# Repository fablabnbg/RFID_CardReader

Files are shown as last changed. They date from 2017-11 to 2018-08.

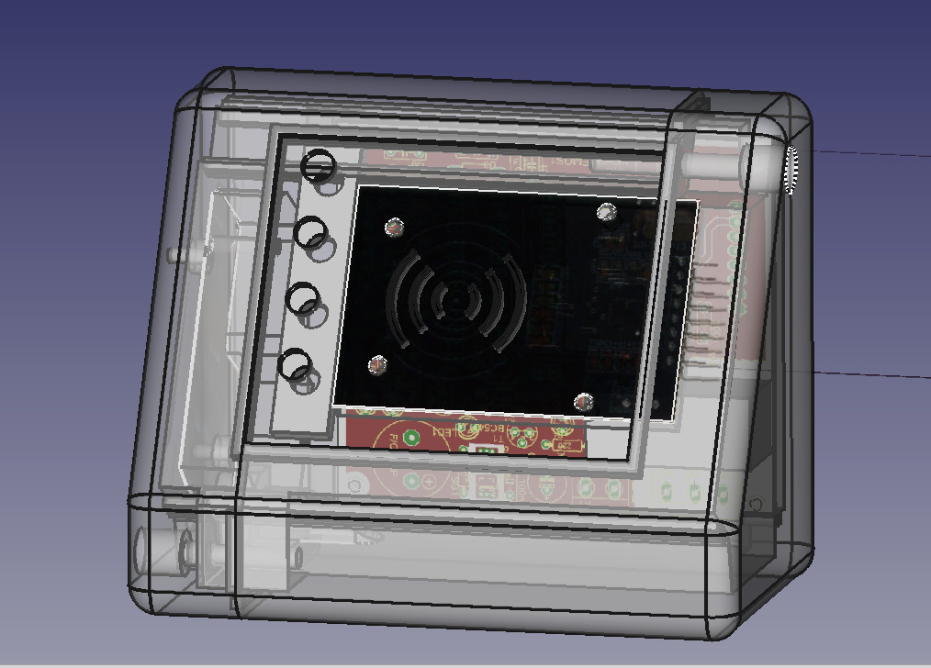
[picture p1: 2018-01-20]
mechanics/gehaeuse_freecad.jpg

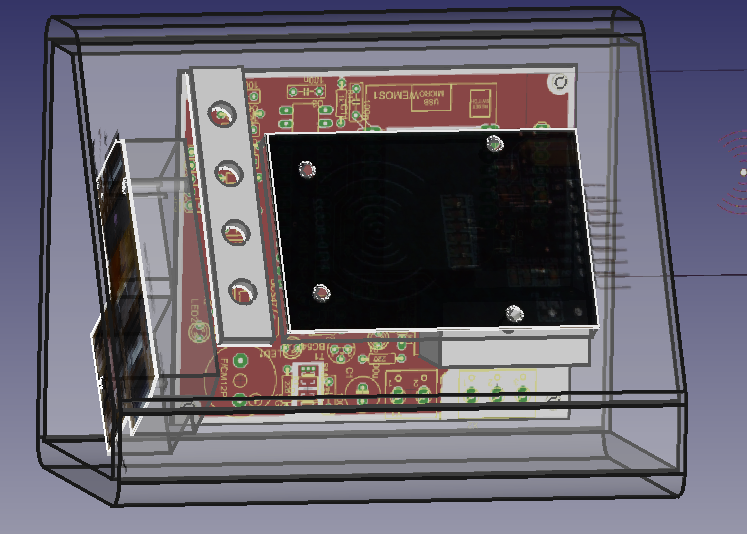
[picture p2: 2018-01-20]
mechanics/Gehäuse-2018-01-03.png

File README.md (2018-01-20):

# RFID_CardReader

A device to read member cards and activate peripheral devices.

## Documentation / Requirements
- See [doc/](doc/) subdirectory for requirements, concepts and schematics

## Software

### ESP
- Example software in subdirectory [Software_ESP](Software_ESP)
- To be built with platformio
- Use "Automaton" library for state machine and WiFi / HTTP connectivity
- Continious integration on travis-ci: 
- For details see [Software_ESP/README.md](Software_ESP/README.md)

### Webserver
 - not yet implemented
 - planning: Use simple server on Raspberry PI

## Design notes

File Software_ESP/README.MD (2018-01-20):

# Software for ESP8266 (Wemos D1 Mini)

## Build

The software should be built with [platformio](http://platformio.org/get-started/cli).

### Prerequisites:

* platformio is installed.
* If necessary, adapt `platformio.ini` to your needs (reset-method, flash-size)`. (Current version is preconfigured for Wemos D1 Mini)
* rename `example_config.h` to `config.h` and edit it to enter your WiFi SSID and password.

### Build on command line:
  * `pio run -t upload`
  * If you want to build, but no upload, enter `pio run`
  
### Build in IDE:
  * You can use Atom or VSCode with installed platformio extension.

## Dependencies

**All dependencies are installed with platformio,** so there is no need to install them manually.

### Automaton

[Automaton](https://github.com/tinkerspy/Automaton/wiki) is a *Reactive state machine framework for Arduino*.
The RFID Cardreader uses automaton to implement the state machine and the to detect the events that trigger state transitions.

*Note:* As the original version support only I/O signals on the internal GPIO pins, currently a [fork](https://github.com/euphi/Automaton) of Automaton is in use.

### Automaton-ESP8266
[Automaton-ESP8266](https://github.com/tinkerspy/Automaton-Esp8266/wiki) is an extension to Automaton to use the event/connector mechanism of Automaton for WIFI Connection and HTTP Client.

*Note:* As the original version has major bugs, currently a [fork](https://github.com/euphi/Automaton-Esp8266) of Automaton-ESP8266 is in use.

### MFRC522

Library to support MFRC522 RFID Reader on SPI.

###	Adafruit MCP23017 Arduino Library

Library to support MCP23017 I/O expander on I2C.

## Software Architecture

### main.cpp

main.cpp defines instances of the MFRC522 card reader and its own state-machine ATM_RFID_Relay as global variables.

#### `setup()`
The `setup()` functions initializes SPI and I2C, "begins" the state machine and starts the WiFi connection and connects the related events (connected, connection lost) to the triggers of the state machine:
```C++
	wifi.begin( ap_ssid, ap_password )
        // NOTE: LED_BUILTIN is RX (UART) on ESP-12, so this interferes with Serial communication on
        // ESP-12 modules (including most Wemos D1, because they also use ESP-12)
        .led( LED_BUILTIN, true ) // Esp8266 built in led shows wifi status
        .onChange(0, relay, ATM_RFIDRelay::EVT_EV_CONNLOST) // directly send an Event from Wifi the the relay state machine
        .onChange(1, relay, ATM_RFIDRelay::EVT_EV_CONNECTED)// "sub-slot" 0: Connection lost; 1: Connected
        .start();
```
  
#### `loop()`

The `loop()` functions cycles the automaton framework, then checks the card reader for new cards and if a new card is present, triggers the state machine with a new request including the UID of the card as parameter.

### ATM_RFIDRelay

This is the state machine class for automaton. So it's derived from Automaton's `Machine` class and adds the `enum`s for states and events.

#### ATM_RFIDRelay.h

The skeleton was created with the [online state machine editor](http://www.wolkendek.nl/atm/index.php) for Automaton.

As private members it defines timers, an instance of the MCP23017 IO expanders, a HTTPClient instance, an input button, and the outputs (LED, Switch, buzzer).

#### ATM_RFIDRelay.cpp

`ATM_RFIDRelay& ATM_RFIDRelay::begin()`
Here the state table is initialized and the sub-statemachines (timers, outputs, inputs, HTTPClient) are configured.

`int ATM_RFIDRelay::event( int id )`

This method is called from the automaton framework every cycle for each possible trigger event. If it returns true the event is triggers.
In ATM_RFIDRelay this is used for the timers only as all other events are triggered externally.

`void ATM_RFIDRelay::action(int id)`

For each state, Automaton allows to define a function for entry, loop or exit.
ATM_RFIDRelay uses this to set the outputs according to the current state.
The automaton "ATM_Led" class allows to set an output to a blink pattern, this is used for some optical or accustical feedback.

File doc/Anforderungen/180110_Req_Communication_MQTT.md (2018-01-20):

# Principle

All communication between the RFID-Cardreader (reader) and the controller is done via MQTT.

Communication follows the [Homie Convention](https://github.com/marvinroger/homie).

If the reader needs to authorize a user, it MUST send an authorisation request to the controller. 

The controller MUST answer the request with an appropriate command to the controller. 

# Homie convention

* The base topic is up the installation. It is recommended to use own base topics for the network of RFID-Cardreaders, e.g. `FLN-Machines`.
* Each device SHOULD be named according to the machine it controlls, e.g. `ZingLaser`.
* *Note: Following the homie convention includes all the default communication from Homie and its Homie-ESP8266 implementation, e.g. advertising of Nodes, frequent information about WiFi quality, uptime, OTA support etc.*

## Nodes

* There MUST be an `AuthReq` node with the property `Token`.
* There MUST be an `State` node with the property `Alert` and the *settable* property `Relais` 
* Other nodes MAY be defined, e.g. to use the device for other functions (e.g. temperature, or current measurement etc.).

## Properties 
### Token (Node Authreq)

* Datatype uint32, no unit

### Relais (Node State)
* Datatype string, no unit
* The string to set the property (controller to reader) MUST be one of the following *enumeration*:
  * `ON_Authorized`: The user has been authorized, so the relais must be switched on.
  * `ON_Override`: The relais must be switched on, although no authorization was requested (override function from server).
  * `OFF_Rejected`: The user has been rejected
  * `OFF_Override`:  The server commands the relais to be switched off.
  * `OFF_locked`: The server commands the relais to be switched off and there SHOULD be no request from the reader to switch it on again (this also SHOULD be visualised on the reader).
  * `OFF_unlocked`: Used to reset the locked state.
* The string to tell the property to the conroller MUST be on of the following *enumeration*:
  * `ON`
  * `OFF`: The relais is off. This includes local reasons to switch the relais off.
  * `ON_override`: The relais has been overridden locally.  
  * *optional* @@@TODO@@@: `OFF_timeout`: The relais has been switched off due to timeout

### Alert
* Datatype: string, no unit
* The string informs the controller of an alert:
  * `OK`: No alert
  * `Intrusion`: Intrusion contacts open
  * @@@TODO@@@: `Override` (this informationis redundant to the Relais state ON_override)
  * Other strings MAY be defined, e.g. `overcurrent`, `powerfail` etc.

## Example:
  
 The base topic is `FLN-Machines` and the device is `Coffee`.
  
 The card reader reads a card of a user that is allowed to use the machine. An authorisation request with the token `CAFEBABE` is to be sent.
 
 Direction           | MQTT Topic                          | MQTT Message
 --------------------|-------------------------------------|-----------------
 reader -> controller|FLN-Machines/Coffee/AuthRequest/Token| CAFEBABE
 controller -> reader|FLN-Machines/Coffee/State/Relais/set | ON_Authorized
 reader -> controller|FLN-Machines/Coffee/State/Relais     | ON
 
 The card reader reads a card of a user that is NOT allowed to use the machine. An authorisation request with the token `ABADCAFE` is to be sent. 

 Direction           | MQTT Topic                          | MQTT Message
 --------------------|-------------------------------------|-----------------
 reader -> controller|FLN-Machines/Coffee/AuthRequest/Token| ABADCAFE
 controller -> reader|FLN-Machines/Coffee/State/Relais/set | OFF_Rejected
 reader -> controller|FLN-Machines/Coffee/State/Relais     | OFF

  # Security
  
  ...tbd...
  
  Keywords:
    * RFID-Security out of scope of communication spec
    * WiFi with strong passwords, on Wifi for machines
    * MQTT TLS (as soon as available in Homie-ESP8266
    * MQTT user authentication
    * MQTT ACLs for topics

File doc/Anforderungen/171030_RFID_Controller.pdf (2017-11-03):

171030_RFID_Controller.docx | 30.10.2017

Roman Jost
Version: v0.1 | 1 / 4 | FabLab Nürnberg

# RFID Control Unit

Technische Spezifikation

Version | Autor | Info
0.1 | RJ | Erste Version. Erstellung einer technischen Spezifikation.

## Inhalt

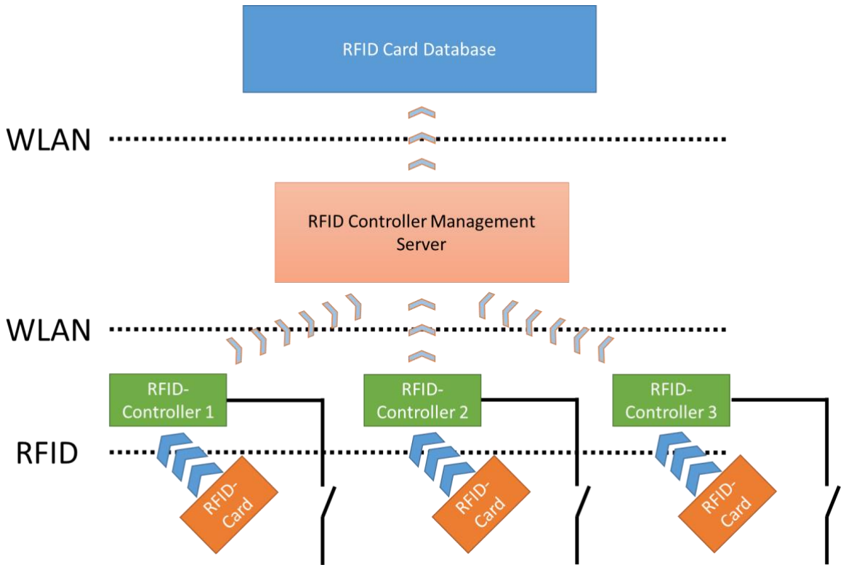
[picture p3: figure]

Version: v0.1 | 2 / 4 | FabLab Nürnberg

## 1.Motivation

Viele Arbeitsplätze und –geräte im FabLab Nürnberg sind ohne Einschränkungen nutzbar, obwohl zum sicheren und pflichtbewussten Arbeiten eine Einweisung nötig wäre. Zudem werden Arbeitsplätze regelmäßig verlassen, ohne für die gewünschte Sauberkeit zu sorgen. Der Verursacher ist in den meisten Fällen nicht mehr nachzuverfolgen.

Ein Lösungsansatz um die aufgelisteten Probleme zu entschärfen ist ein RFID Controller. Dieser Controller ist ein eigenständiges Gerät, welches die RFID Mitgliedskarten einlesen kann. Die so gewonnenen Informationen werden an einen zentralen Server übergeben, welcher die Berechtigungen des Mitglieds dem Controller übermittelt. Abhängig von den Berechtigungen kann der Controller nun entweder die Benutzung gewähren oder verweigern.

Der RFID Controller kann vielseitig eingesetzt werden:

- Freischaltung von Geräten.
- An- und Abmeldung von Mitgliedern an Arbeitsplätzen.
- Entriegelung von abgeschlossenen Objekten (Schlüsselkasten, Kühlschrank)

Anhand eines Logbuchs auf dem Server kann zudem jederzeit nachverfolgt werden, welches Mitglied wann eine Anfrage bei einem der Controller gestellt hat.

## 2. Technische Spezifikation

### 2.1 Übersicht

Einzelne RFID-Controller kommunizieren mittels Funkverbindung (Vorzugsweise WLAN) mit einem Server. Der Server kann an einer weiteren Stelle die Berechtigungen des Mitglieds anhand der Karten-ID feststellen und ein Access/Deny an den Controller zurücksenden.

Version: v0.1 | 3 / 4 | FabLab Nürnberg

Sobald der Server eine positive Antwort zurück sendet, kann der RFID-Controller die Peripherie freigeben.

### 2.2 Hardware

Der Hardware Controller soll im Wesentlichen aus zwei Modulen bestehen: Als Mikrocontroller kommt der ESP8266 zum Einsatz. Dieser verfügt über ein integriertes WLAN Modul und eine SPI-Schnittstelle. Via WLAN wird mit dem Server kommuniziert, die SPI-Schnittstelle dient zum Datenaustausch mit dem RFID Modul. Das RFID Modul ist ein MFRC522, dieses wurde schon bei der Tür-Schließanlage am FabLab Eingang eingesetzt und hat mit seiner fehlerfreien Arbeitsweise überzeugt. Zudem gibt es schon eine fertige Bibliothek mit Beispiel-Applikationen für das MFRC522.

Weiterhin sollen noch folgende Eigenschaften realisiert werden:

| • Eine Power LED → Betriebsspannung OK • Eine „Connection to Server“ LED → Verbindung zum Server aktiv • Eine „Transmit Receive“ LED → Daten werden übertragen (Eine LED für beide Richtungen) • Eine „Status“ LED → „Gerät / Arbeitsplatz freigeschaltet“ • Im Störungsfall soll durch einen kleinen Hardware Eingriff der Controller überbrückt werden können. Dies könnte man durch einen Jumper oder Mikroschalter umsetzen. Dieses Bauteil sollte jedoch nicht so einfach zugänglich sein, sodass die Controller-Module nicht ständig überbrückt werden. Die Überbrückung sollte so aufgebaut werden, dass diese von der Firmware geprüft werden kann. • Ein Summer soll für mehr Rückmeldung an den Anwender sorgen. Kurze Tonimpulse falls eine Karte erkannt wurde, weitere kurze Tonimpulse wenn eine Freischaltung erfolgt ist. Längere, eindringlichere Töne, falls eine Störung oder keine Berechtigung vorliegt. • Die Hardware sollte einfach reproduzierbar sein. Es sollten keine Bauteile eingesetzt werden, die man nicht manuell löten kann, sodass diese Module einfach zu bestücken sind. • Die Module sollten über eine feste Spannungsversorgung betrieben werden. Ein Miniatur Schaltnetzteil wäre wünschenswert. Die Sekundärspannung sollte 5V betragen. • Als Schalter sollte ein 5V Relais vorgesehen werden. Das Relais sollte einen Strom von 16A über den Schalter verkraften können. • Zwischen Schaltkontakt, Schaltnetzteil und der restlichen Verschaltung sollte ein Sicherheits- abstand auf der Platine gewahrt werden (Luft- und Kriechstrecken). • Das Board sollte Schraubklemmen für die Schaltkontakte des Relais vorsehen. • Ein Kontakt, der das Öffnen des Gehäuses detektiert, wäre sinnvoll.

Als Server soll ein Raspberry Pi zum Einsatz kommen. Dieser dient als Access Point und baut sein eigenes, isoliertes WLAN auf. Die RFID Controller melden sich in diesem WLAN an und versuchen eine Verbindung mit der Server Applikation aufzubauen.

### 2.3 Software

Die Controller Module werden mittels der Arduino IDE programmiert. Die Firmware baut eine Verbindung zum Server auf und schickt ihm die Karten-ID zu, sobald eine RFID-Karte lesbar ist. Die Firmware soll folgende Aufgaben übernehmen:

| • Kommunikation mit dem Server • Kommunikation mit dem RFID Lese-Modul • Die Firmware sollte die Peripherie (bis auf die Power-OK LED) steuern. • Im Falle einer Überbrückung des Kontakts sollte ein Signal in einem regelmäßigen Zeitabstand ausgegeben werden (Beschleunigen der Störungsbehebung).

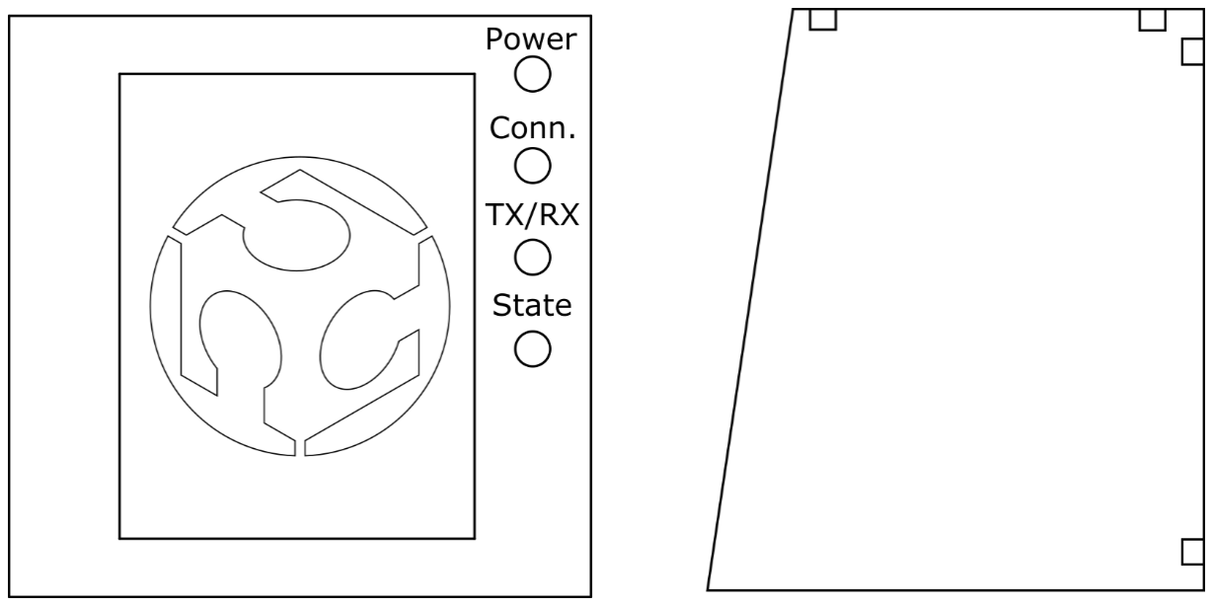
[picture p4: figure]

Version: v0.1 | 4 / 4 | FabLab Nürnberg

Der Server übernimmt folgende Aufgaben:

- Aufbau eines Access Points (isoliertes WLAN Netz).
- Ständige Annahme von Verbindungen und Anfragen.
- Abfrage der Berechtigungen in einer Datenbank. Dabei sind zwei Methoden denkbar: Regelmäßige Kopie der Datenbank in einen lokalen Speicher oder die Just-in-time Abfrage der Karten-Daten.
- Überprüfung der Berechtigungen anhand der Karten-ID.
- Rücksendung Access/Deny nach der Überprüfung.
- Schreiben und Speicherverwaltung von Log-Dateien.

### 2.4 Mechanik

Die Mechanik umfasst das Gehäuse, in welches die Hardware integriert wird. Es sollte weiterhin genügend Platz für eine Verkabelung vorgesehen werden. Zudem sollte das Gehäuse über diverse Montagemöglichkeiten verfügen. Das Gehäuse sollte aus zwei Teilen bestehen, sodass es im installierten Zustand geöffnet werden kann. Eine weitere Öffnung zum Erreichen der Not-Überbrückung wäre sinnvoll. Die LEDs sollten am Gehäuse so ausgerichtet werden, dass sie beim Betätigen des RFID Controllers gut zu sehen sind. Der Karten-Lesebereich sollte gekennzeichnet werden (vorzugsweise durch ein FabLab Logo ). Teile der Schaltung, welche gefährlich hohe Spannungen vorweisen, sollten mit einem Berührungsschutz ausgerüstet werden (Netzteil, Relaiskontakte).

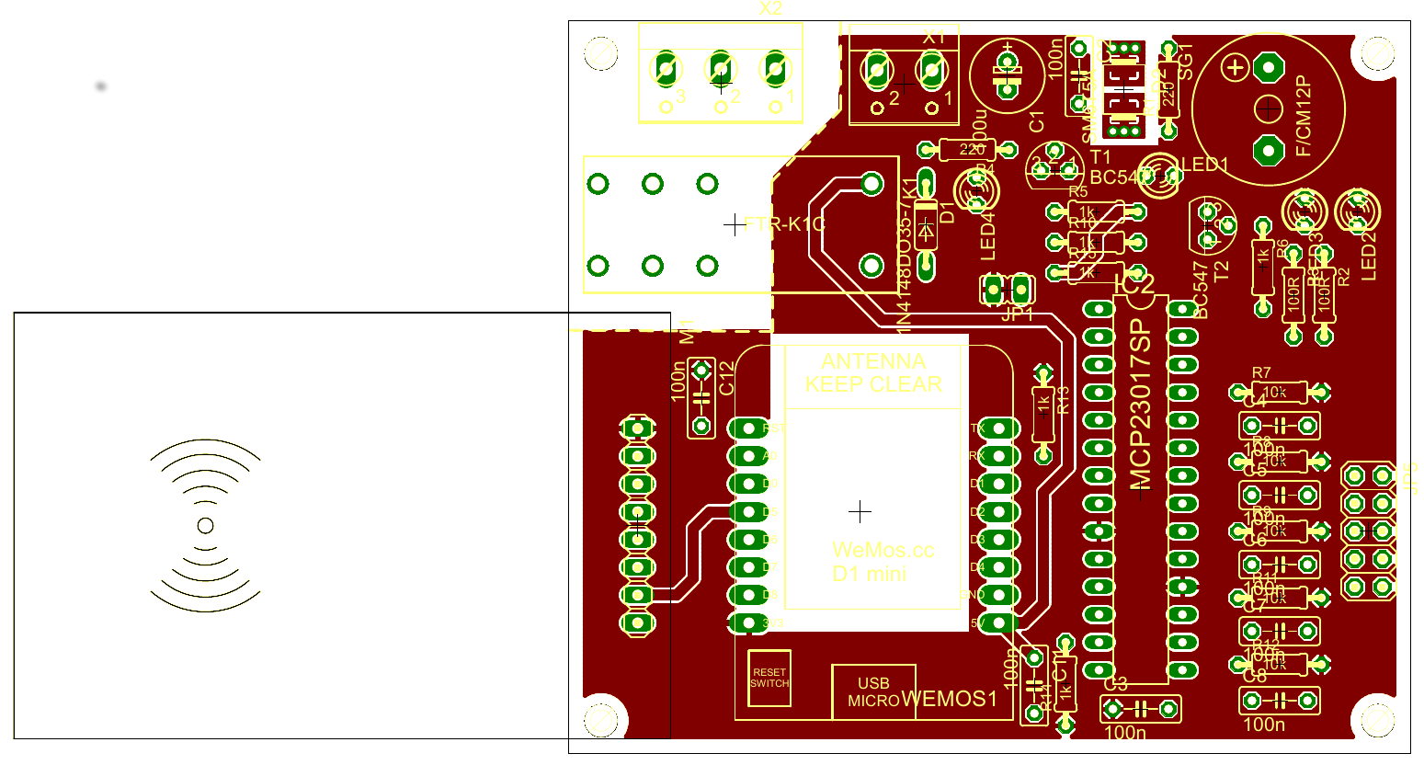
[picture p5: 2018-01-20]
mechanics/pcb_layout_top.png

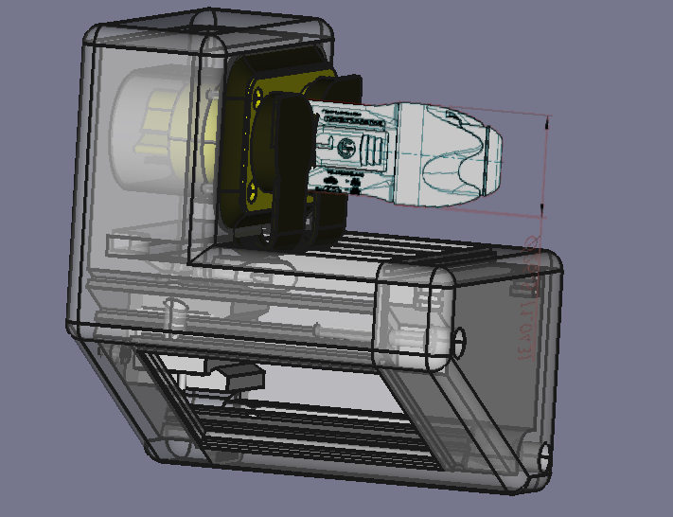
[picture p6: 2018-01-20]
mechanics/Gehäuse-TrueCon-2018-01-08.png

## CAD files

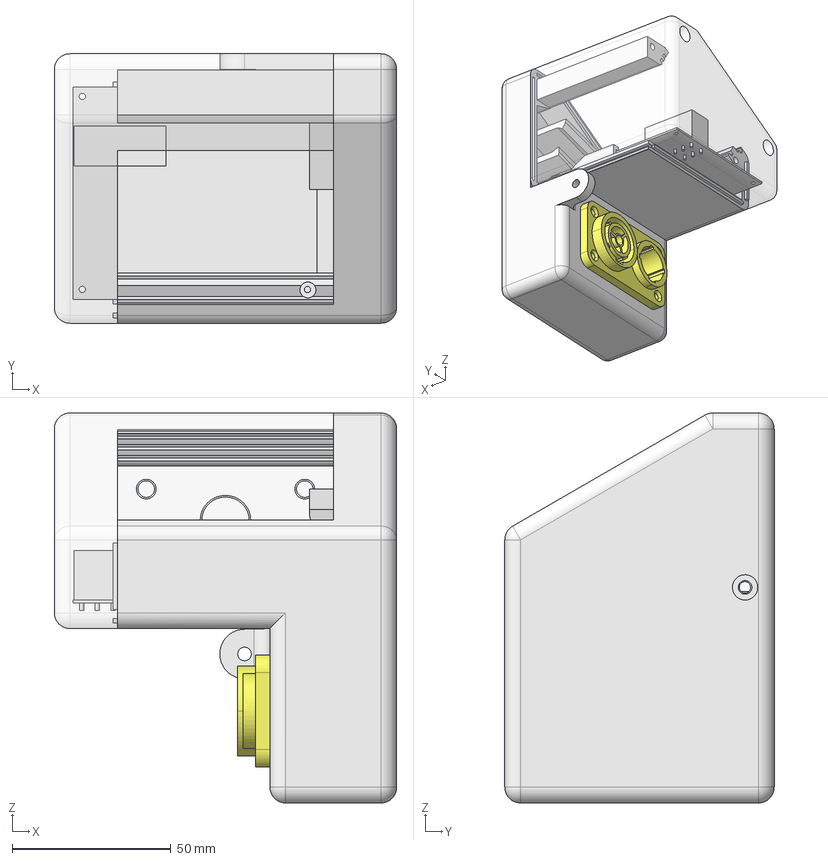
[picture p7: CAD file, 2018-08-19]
mechanics/Gehaeuse.fcstd
108.0 x 85.0 x 123.0 mm
pcb-layout
gehaeuse rechts
D-NAC3PX

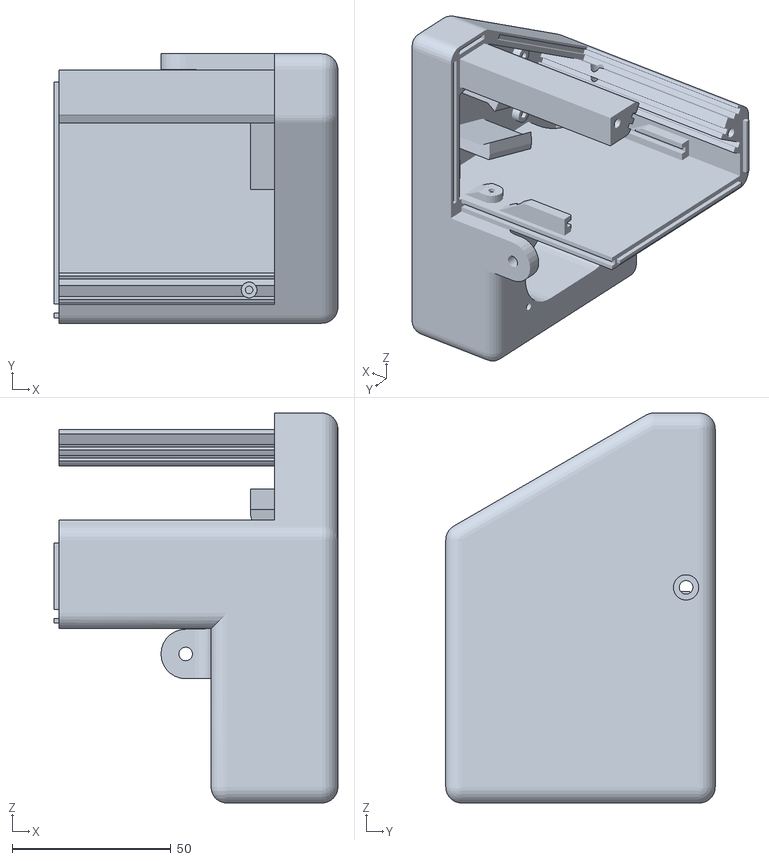
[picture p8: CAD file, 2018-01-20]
mechanics/gehaeuse_links_truecon.stl
89.5 x 85.0 x 123.0

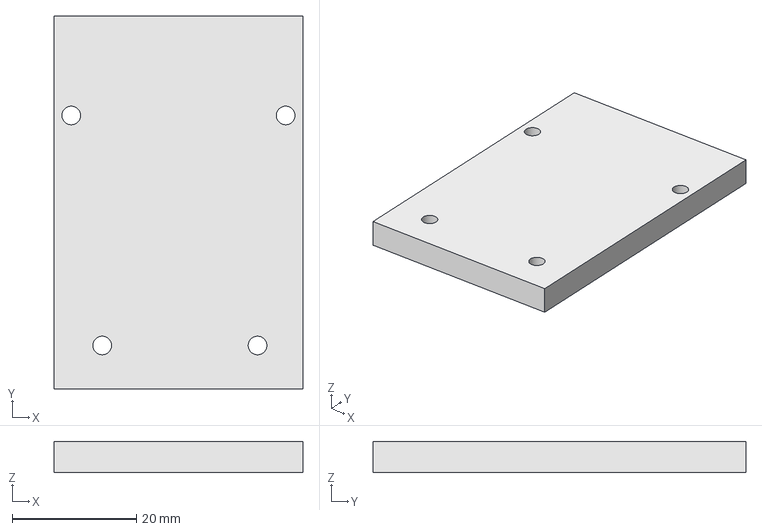
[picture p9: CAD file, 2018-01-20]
mechanics/MFRC522-Module.fcstd
40.0 x 60.0 x 5.00 mm

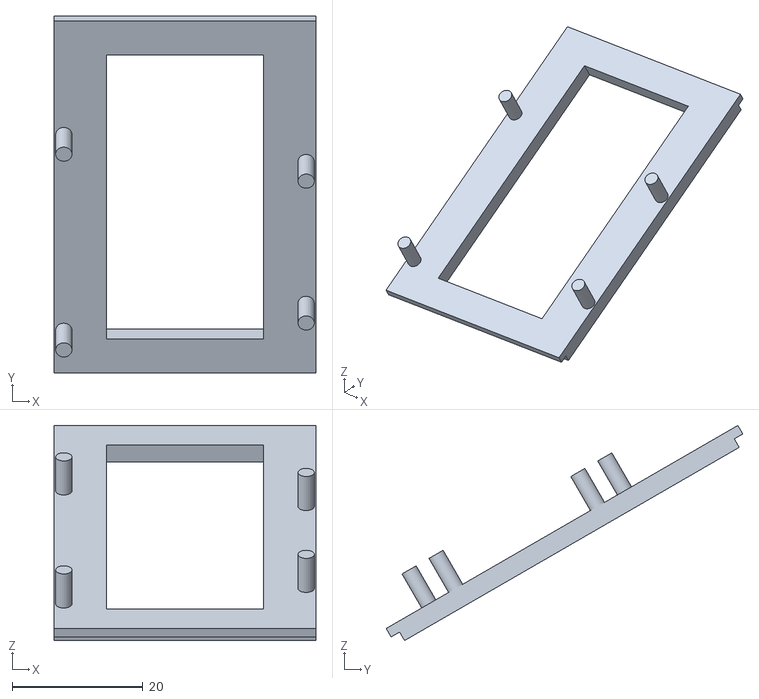
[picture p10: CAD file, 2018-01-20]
mechanics/mfrc522_halter.stl
40.0 x 54.4 x 32.8

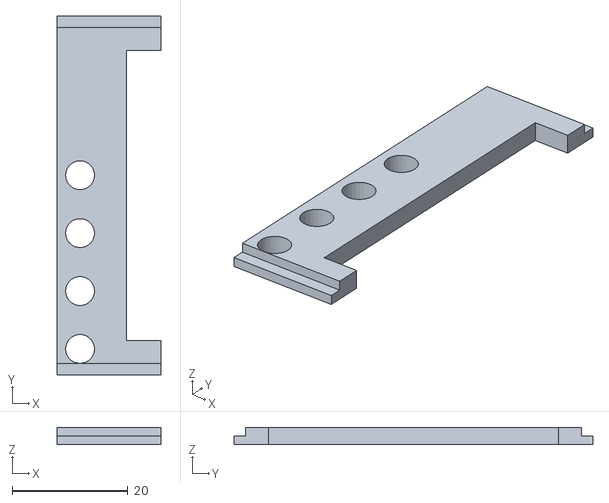
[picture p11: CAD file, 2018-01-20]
mechanics/led_halter_5mm.stl
18.0 x 62.0 x 3.00

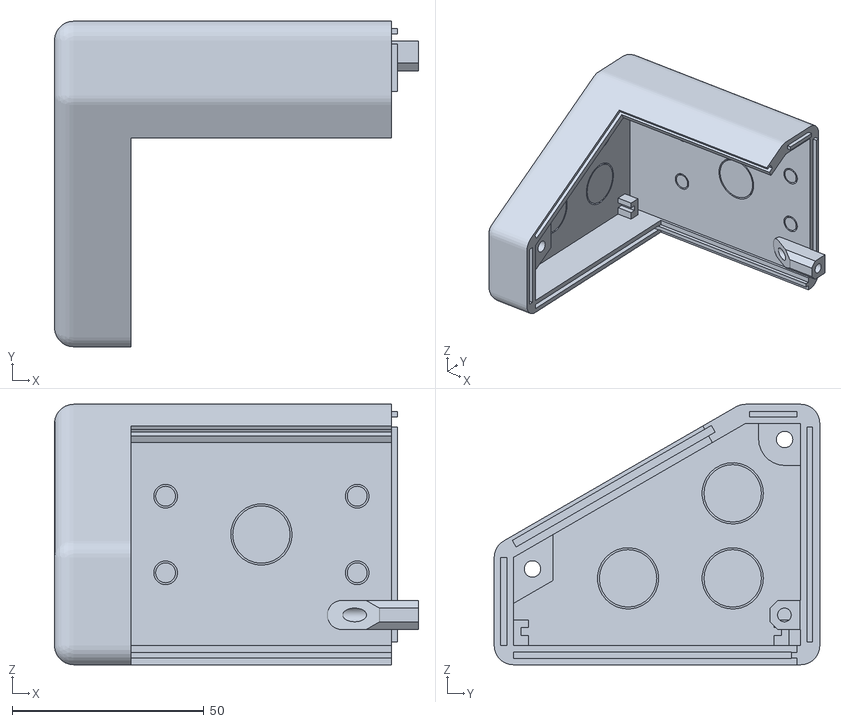
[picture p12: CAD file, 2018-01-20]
mechanics/gehaeuse_rechts.stl
95.0 x 85.0 x 68.0

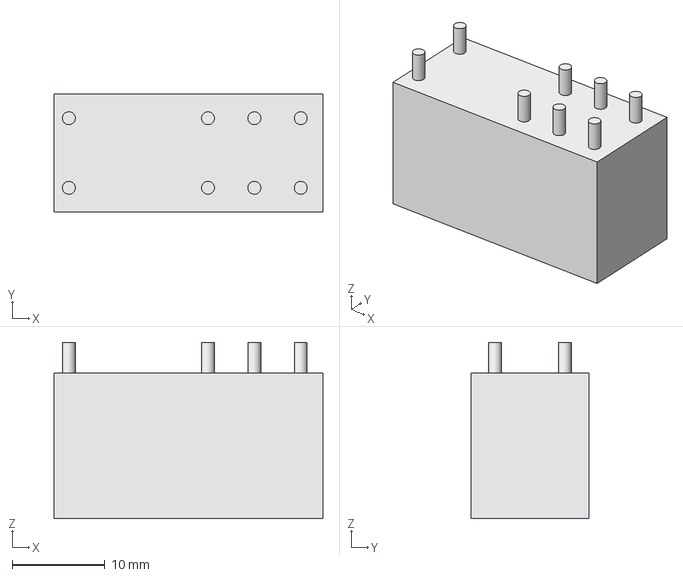
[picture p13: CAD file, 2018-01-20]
mechanics/Relais-FTR-K1.fcstd
29.0 x 12.7 x 19.0 mm

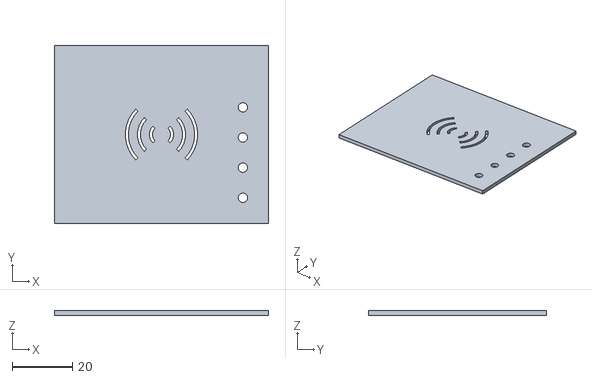
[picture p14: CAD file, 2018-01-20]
mechanics/frontplatte.stl
71.0 x 59.0 x 1.50

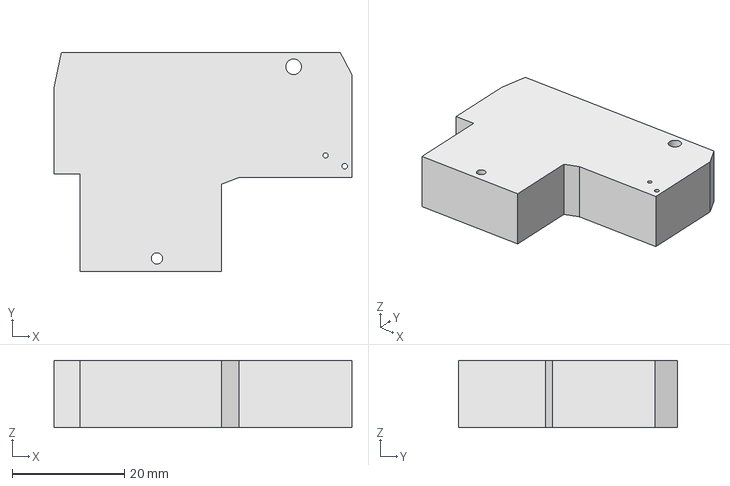
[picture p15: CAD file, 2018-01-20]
mechanics/Netzteil.fcstd
53.0 x 39.0 x 12.0 mm

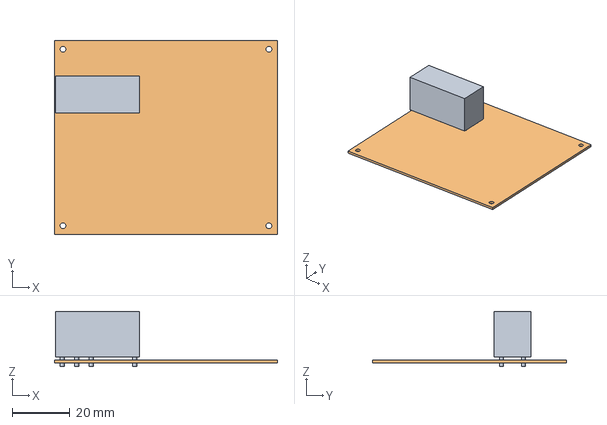
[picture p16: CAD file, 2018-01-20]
mechanics/pcb-layout.fcstd
76.9 x 66.9 x 19.0 mm
Relais-FTR-K1

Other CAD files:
mechanics/led_halter_3mm.stl
mechanics/Gehaeuse.stl
mechanics/MFRC522-Module.stl
mechanics/Relais-FTR-K1.stl

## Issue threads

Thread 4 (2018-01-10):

Spezifikation Kommunikation Controller (Server) - Reader

euphi, 2018-01-10:
Solange wir unter uns sind, schlage ich vor, die technischen Diskussionen auf deutsch zu führen.

- [ ] #4 Variante MQTT
- [ ] #5 Variante HTTP
- [ ] #6 Variante eigenes Protokoll

Vor-/Nachteile der Varianten:

...

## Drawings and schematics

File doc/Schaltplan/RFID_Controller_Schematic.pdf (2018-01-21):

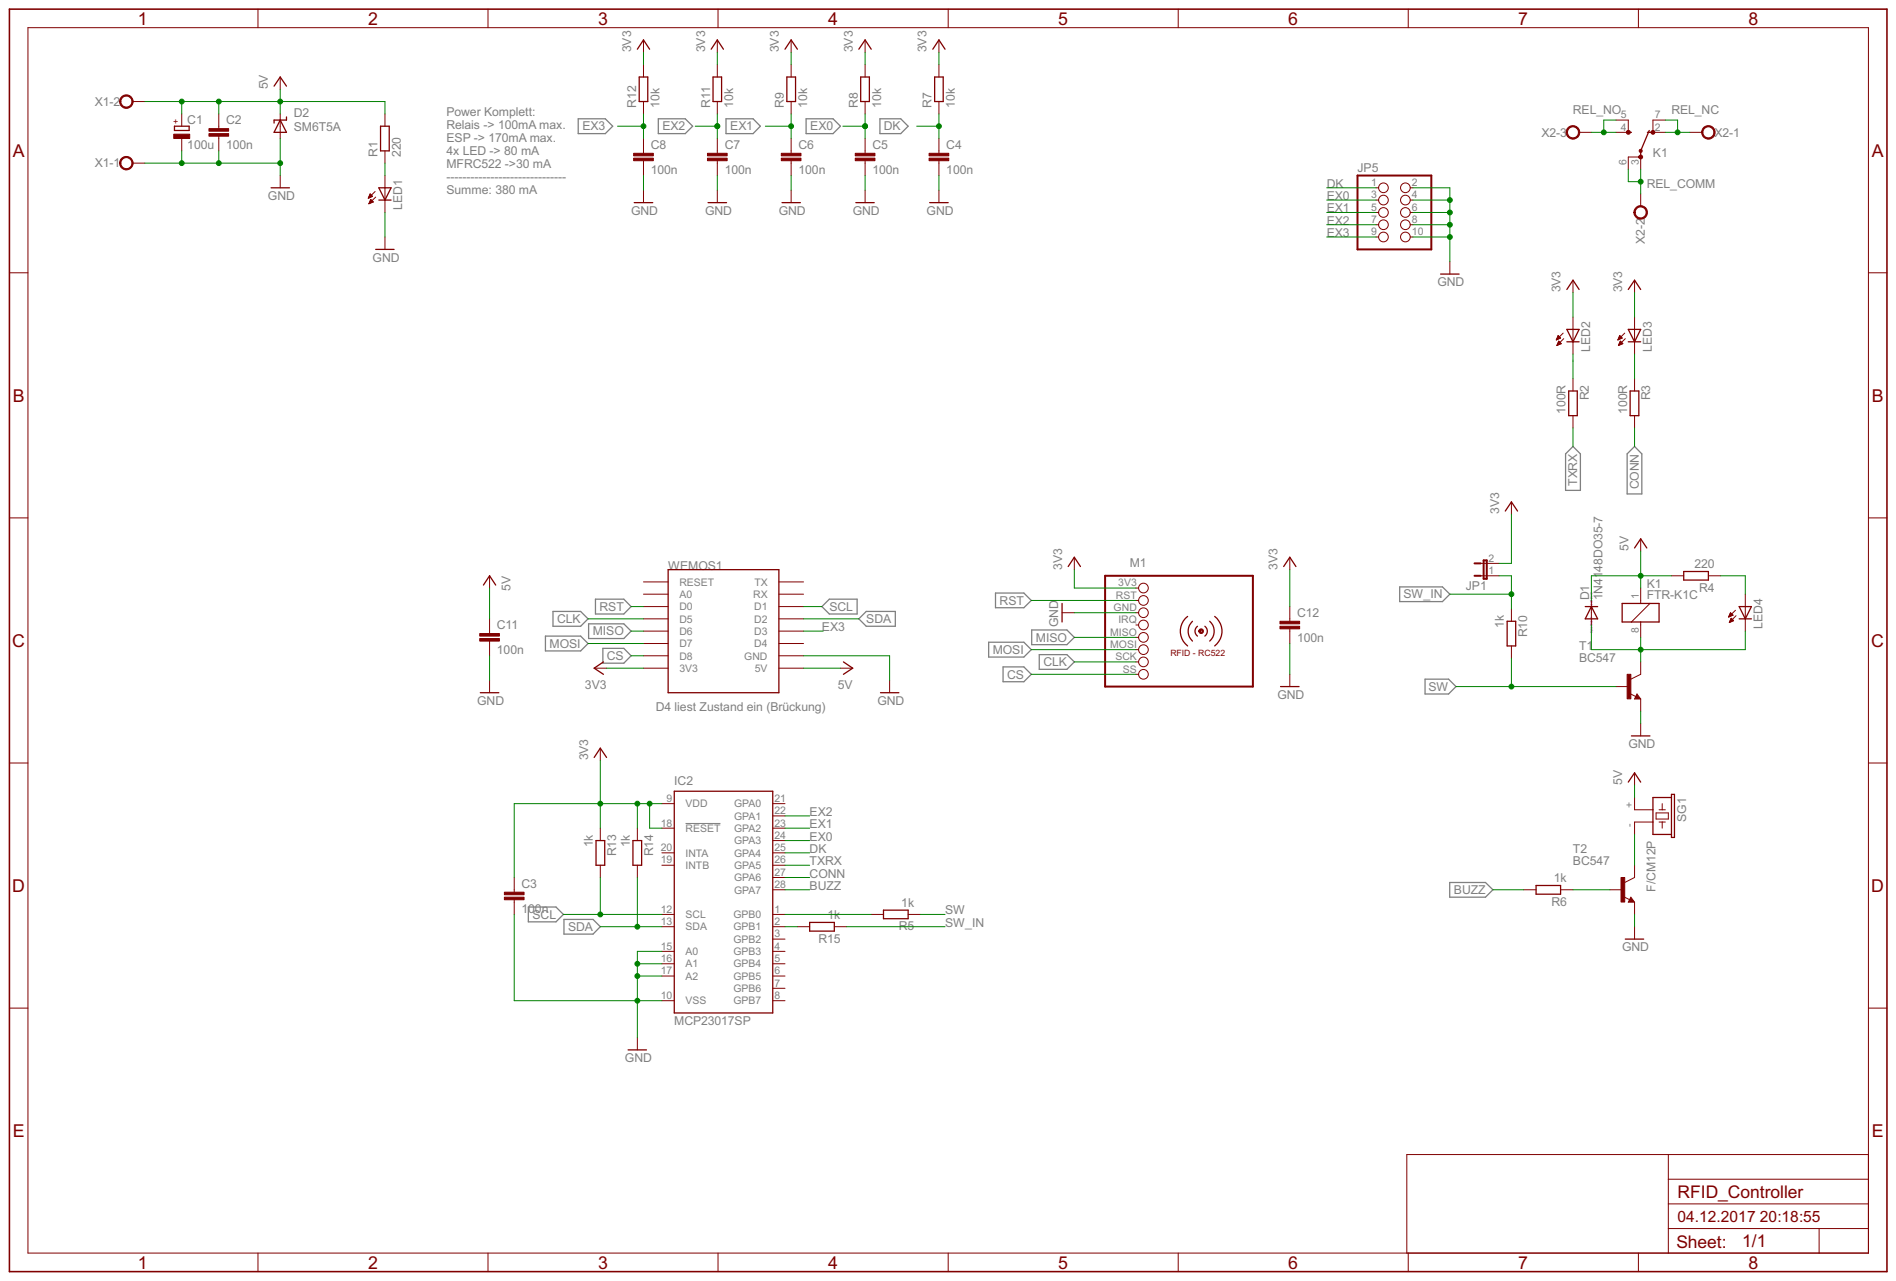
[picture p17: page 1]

Power Komplett: Relais -> 100mA max. ESP -> 170mA max. 4x LED -> 80 mA MFRC522 ->30 mA

IRQ MISO MOSI SCK

D4 liest Zustand ein (Brückung)

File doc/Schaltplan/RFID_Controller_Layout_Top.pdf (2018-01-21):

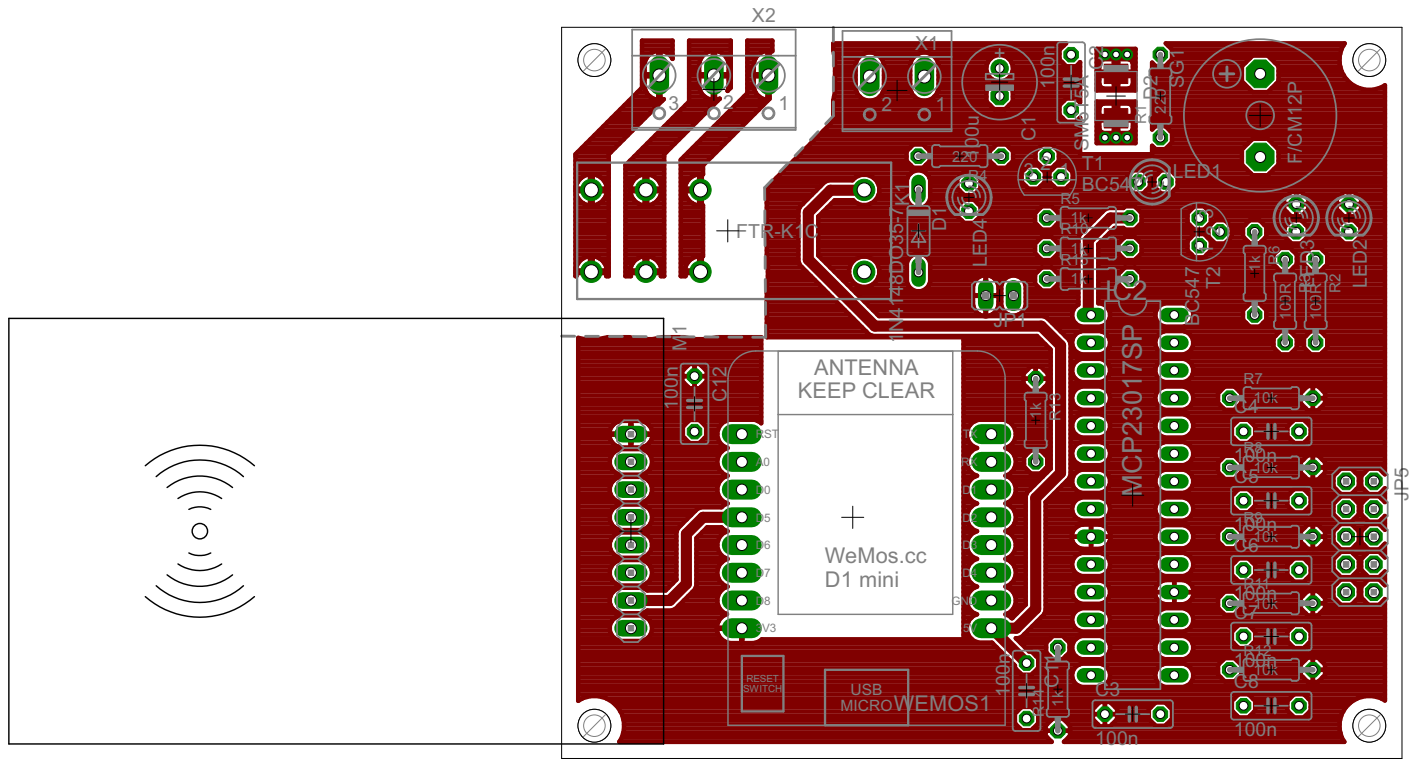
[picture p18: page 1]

RESET SWITCH | | C8

USB

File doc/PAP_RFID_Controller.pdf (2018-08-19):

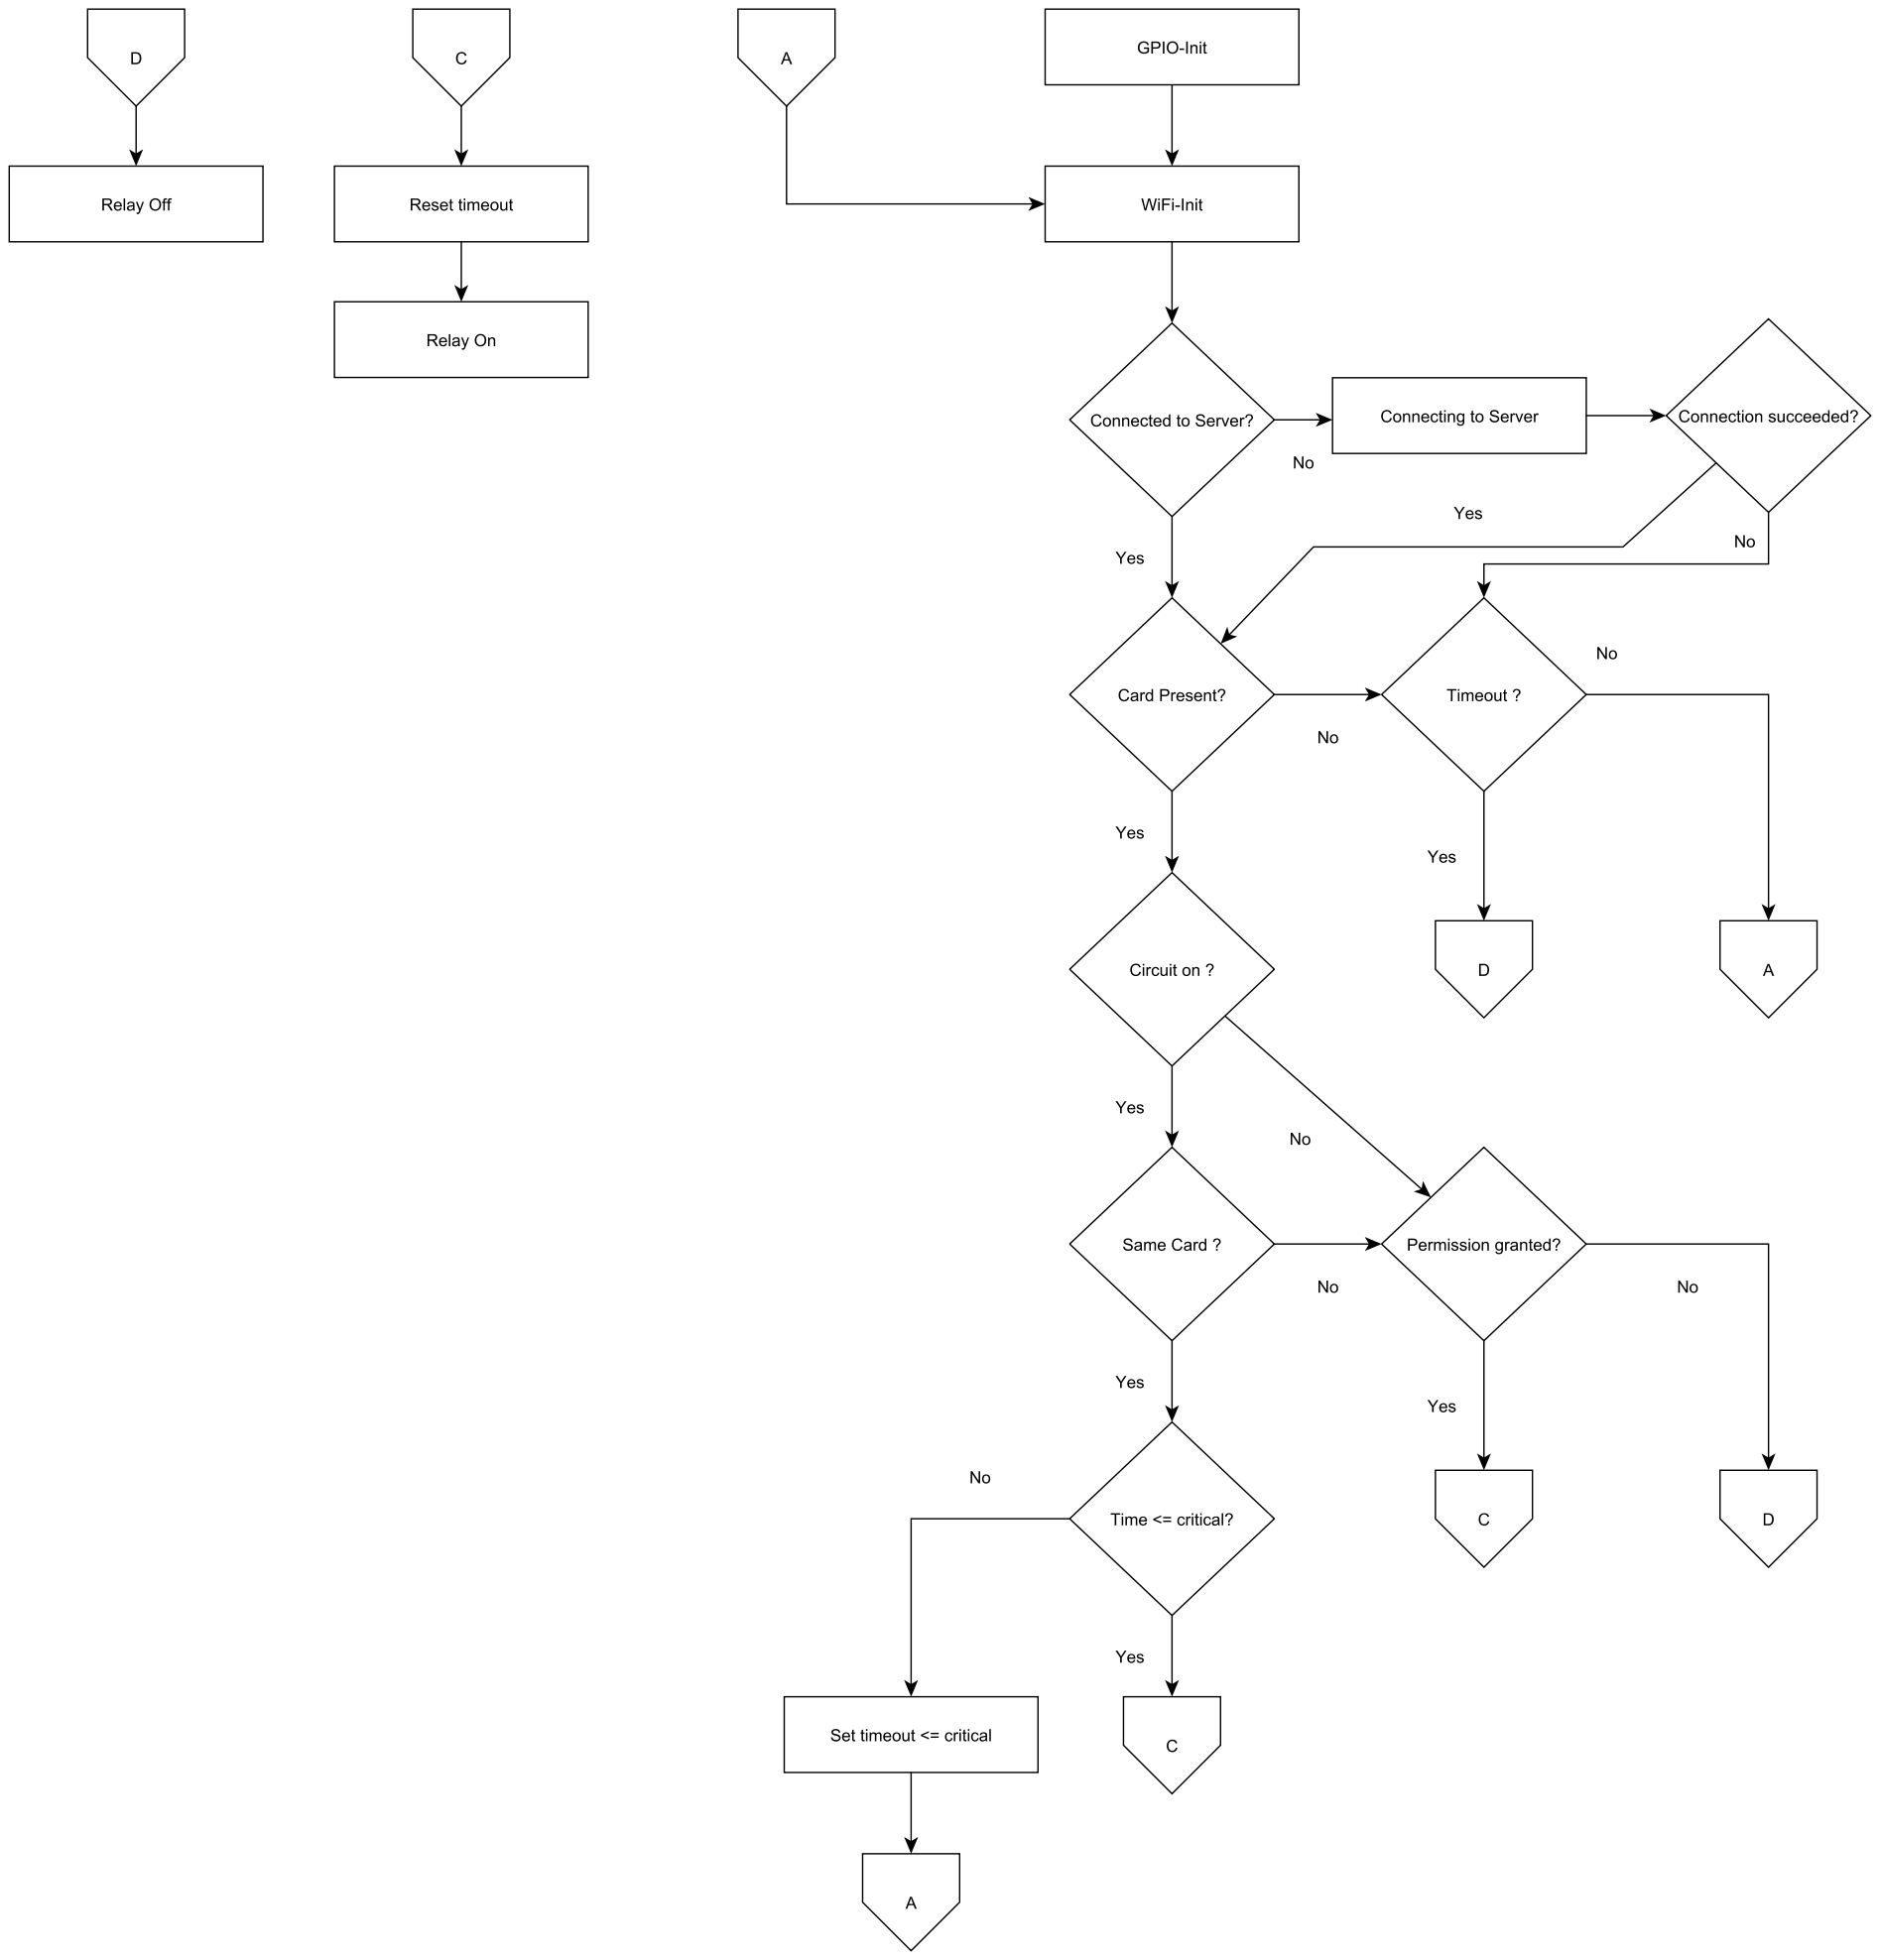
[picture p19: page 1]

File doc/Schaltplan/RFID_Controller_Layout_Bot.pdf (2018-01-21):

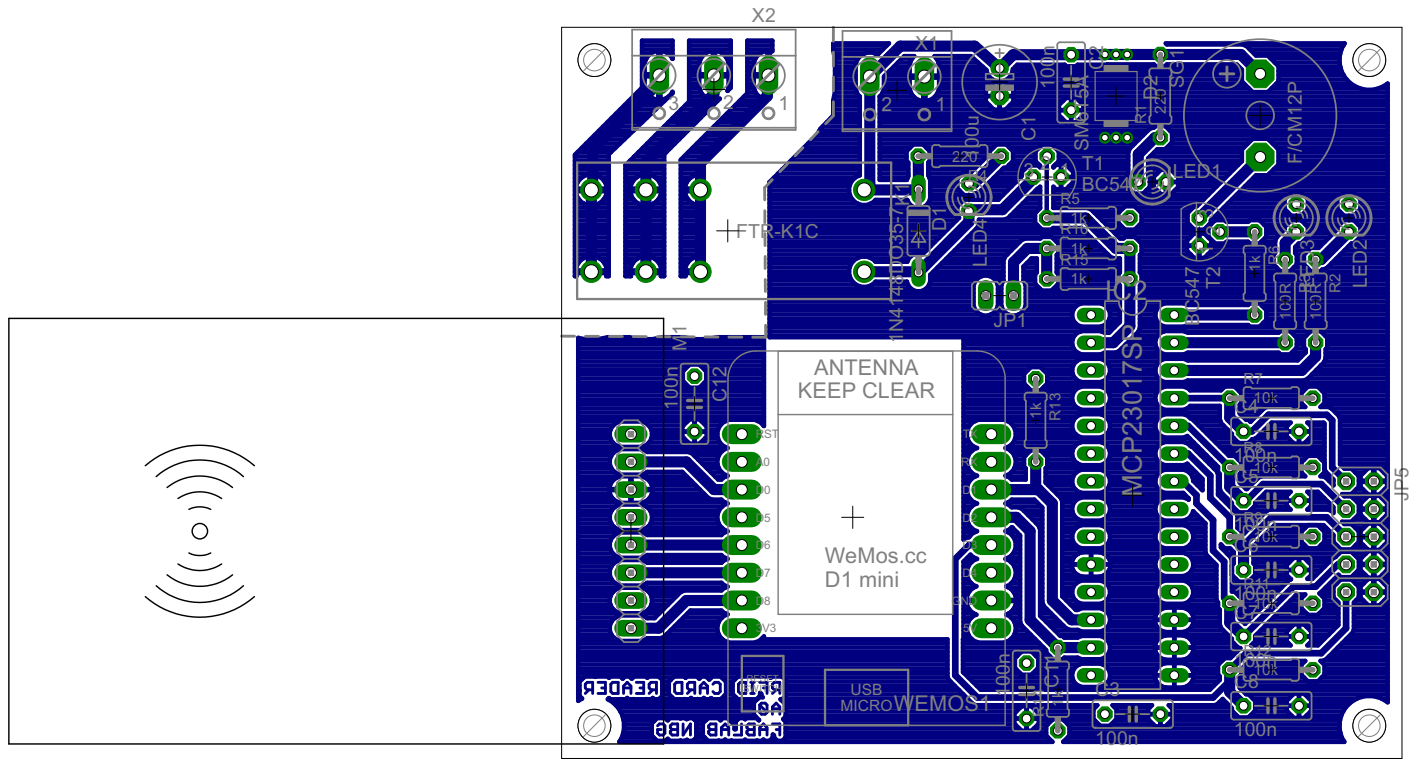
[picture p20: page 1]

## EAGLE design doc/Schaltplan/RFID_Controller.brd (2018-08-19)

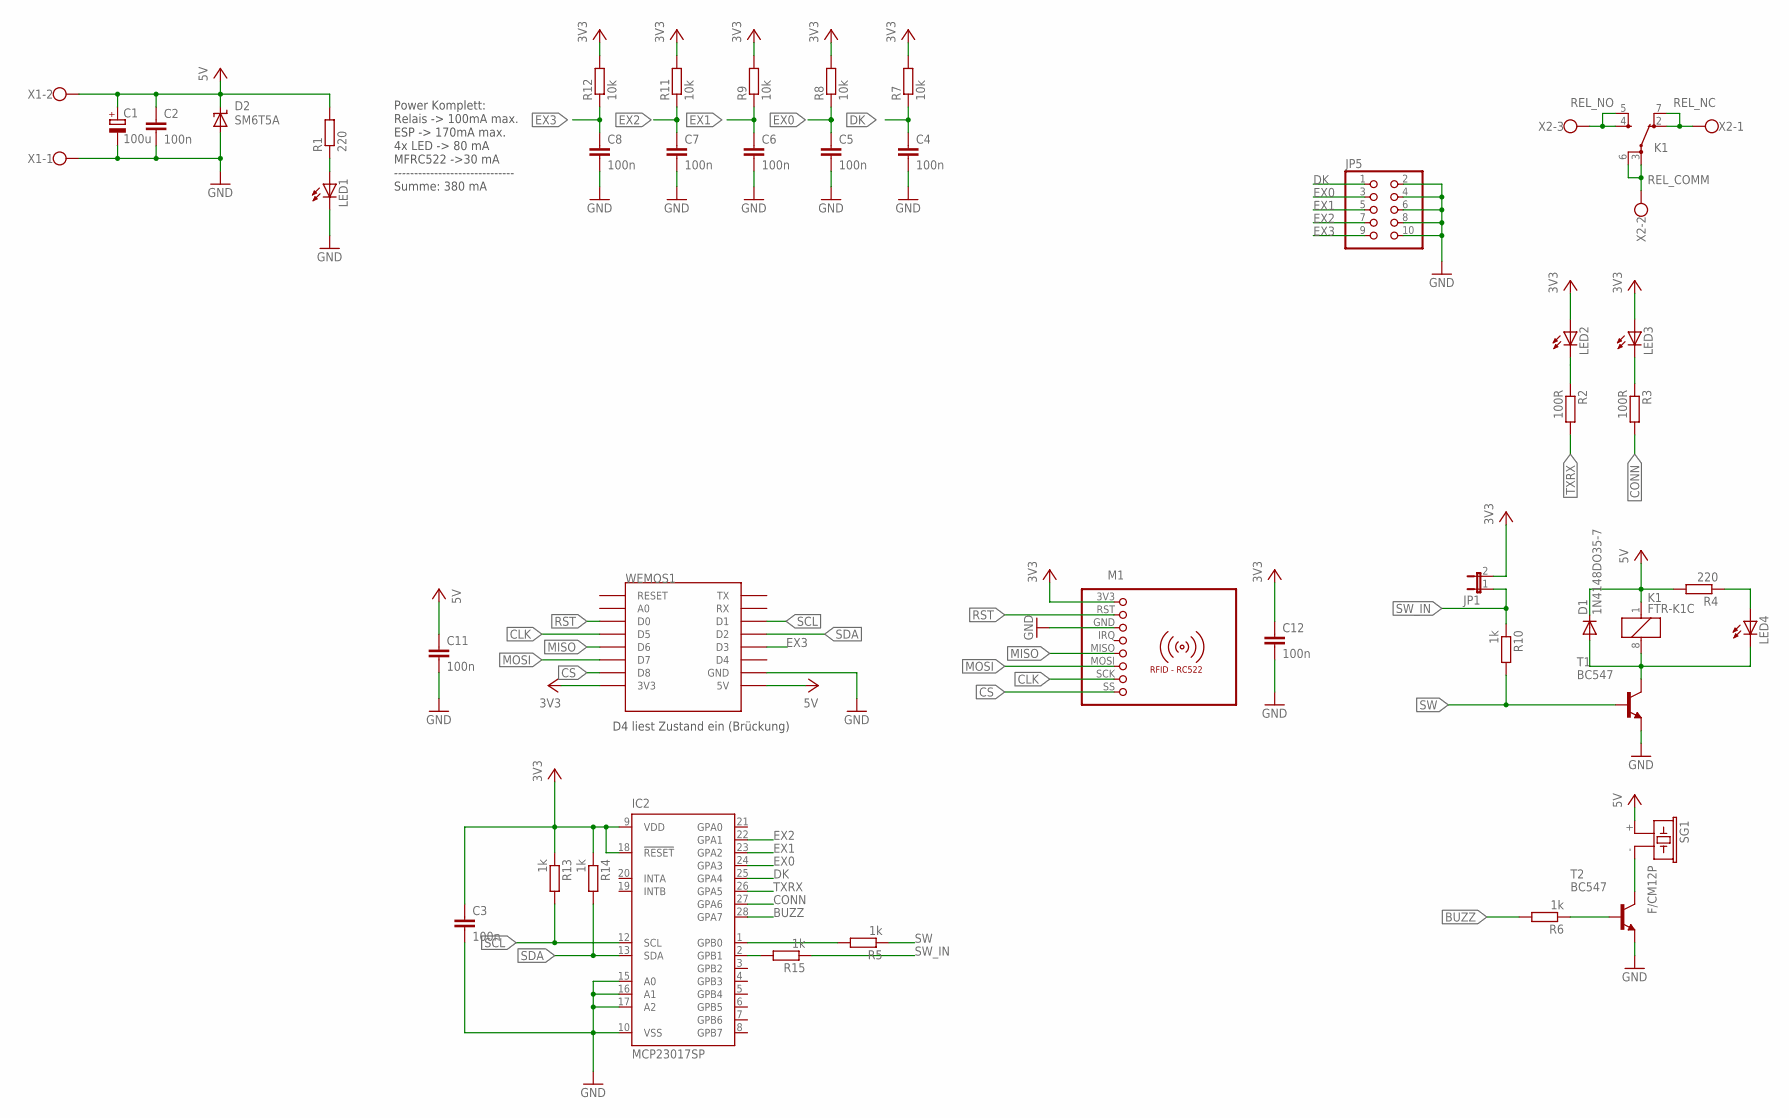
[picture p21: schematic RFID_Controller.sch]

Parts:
C1: 100u; E2,5-7
C2, C3, C4, C5, C6, C7, C8, C11, C12: 100n; C050-025X075
D1: 1N4148DO35-7; DO35-7
D2: SM6T5A; SMBJ
IC2: MCP23017SP; DIL28-3
JP1: JP1E; JP1
JP5: PINHD-2X5; 2X05
K1: FTR-K1C
LED1, LED2, LED3, LED4: LED3MM
M1: RFID-RC522
R1, R4: 220; 0204/7
R2, R3: 100R; 0204/7
R5, R6, R10, R13, R14, R15: 1k; 0204/7
R7, R8, R9, R11, R12: 10k; 0204/7
SG1: F/CM12P
T1, T2: BC547; TO92
WEMOS1: WEMOS-D1-MINI
X1: W237-102
X2: W237-103

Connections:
3V3: C3.1, C12.1, IC2.9 (VDD), IC2.18 (!RESET), JP1.2, LED2.A, LED3.A, M1.3V3 (1), R7.2, R8.2, R9.2, R11.2, R12.2, R13.1, R14.1, WEMOS1.3V3
5V: C1.+, C2.1, C11.1, D1.C, D2.C, K1.1, R1.2, R4.2, SG1.+ (1), WEMOS1.5V, X1.2
BUZZ: IC2.28 (GPA7), R6.2
CLK: M1.SCK (7), WEMOS1.D5
CONN: IC2.27 (GPA6), R3.2
CS: M1.SS (8), WEMOS1.D8
DK: C4.1, IC2.25 (GPA4), JP5.1, R7.1
EX0: C5.1, IC2.24 (GPA3), JP5.3, R8.1
EX1: C6.1, IC2.23 (GPA2), JP5.5, R9.1
EX2: C7.1, IC2.22 (GPA1), JP5.7, R11.1
EX3: C8.1, JP5.9, R12.1, WEMOS1.D3
GND: C1.-, C2.2, C3.2, C4.2, C5.2, C6.2, C7.2, C8.2, C11.2, C12.2, D2.A, IC2.10 (VSS), IC2.15 (A0), IC2.16 (A1), IC2.17 (A2), JP5.2, JP5.4, JP5.6, JP5.8, JP5.10, LED1.K (C), M1.GND (3), T1.1 (E), T2.1 (E), WEMOS1.GND, X1.1
MISO: M1.MISO (5), WEMOS1.D6
MOSI: M1.MOSI (6), WEMOS1.D7
unnamed: LED1.A, R1.1
unnamed: LED2.K (C), R2.1
unnamed: LED3.K (C), R3.1
unnamed: LED4.A, R4.1
unnamed: D1.A, K1.8 (2), LED4.K (C), T1.3 (C)
unnamed: R6.1, T2.2 (B)
unnamed: SG1.- (2), T2.3 (C)
unnamed: IC2.1 (GPB0), R5.2
unnamed: IC2.2 (GPB1), R15.2
REL_COMM: K1.3 (PA), K1.6 (PB), X2.2
REL_NC: K1.2 (OA), K1.7 (OB), X2.1
REL_NO: K1.4 (SA), K1.5 (SB), X2.3
RST: M1.RST (2), WEMOS1.D0
SCL: IC2.12 (SCL), R13.2, WEMOS1.D1
SDA: IC2.13 (SDA), R14.2, WEMOS1.D2
SW: R5.1, R10.2, T1.2 (B)
SW_IN: JP1.1, R10.1, R15.1
TXRX: IC2.26 (GPA5), R2.2

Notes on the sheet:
Power Komplett: Relais -> 100mA max. ESP -> 170mA max. 4x LED -> 80 mA MFRC522 ->30 mA ------------------------------ Summe: 380 mA
D4 liest Zustand ein (Brückung)

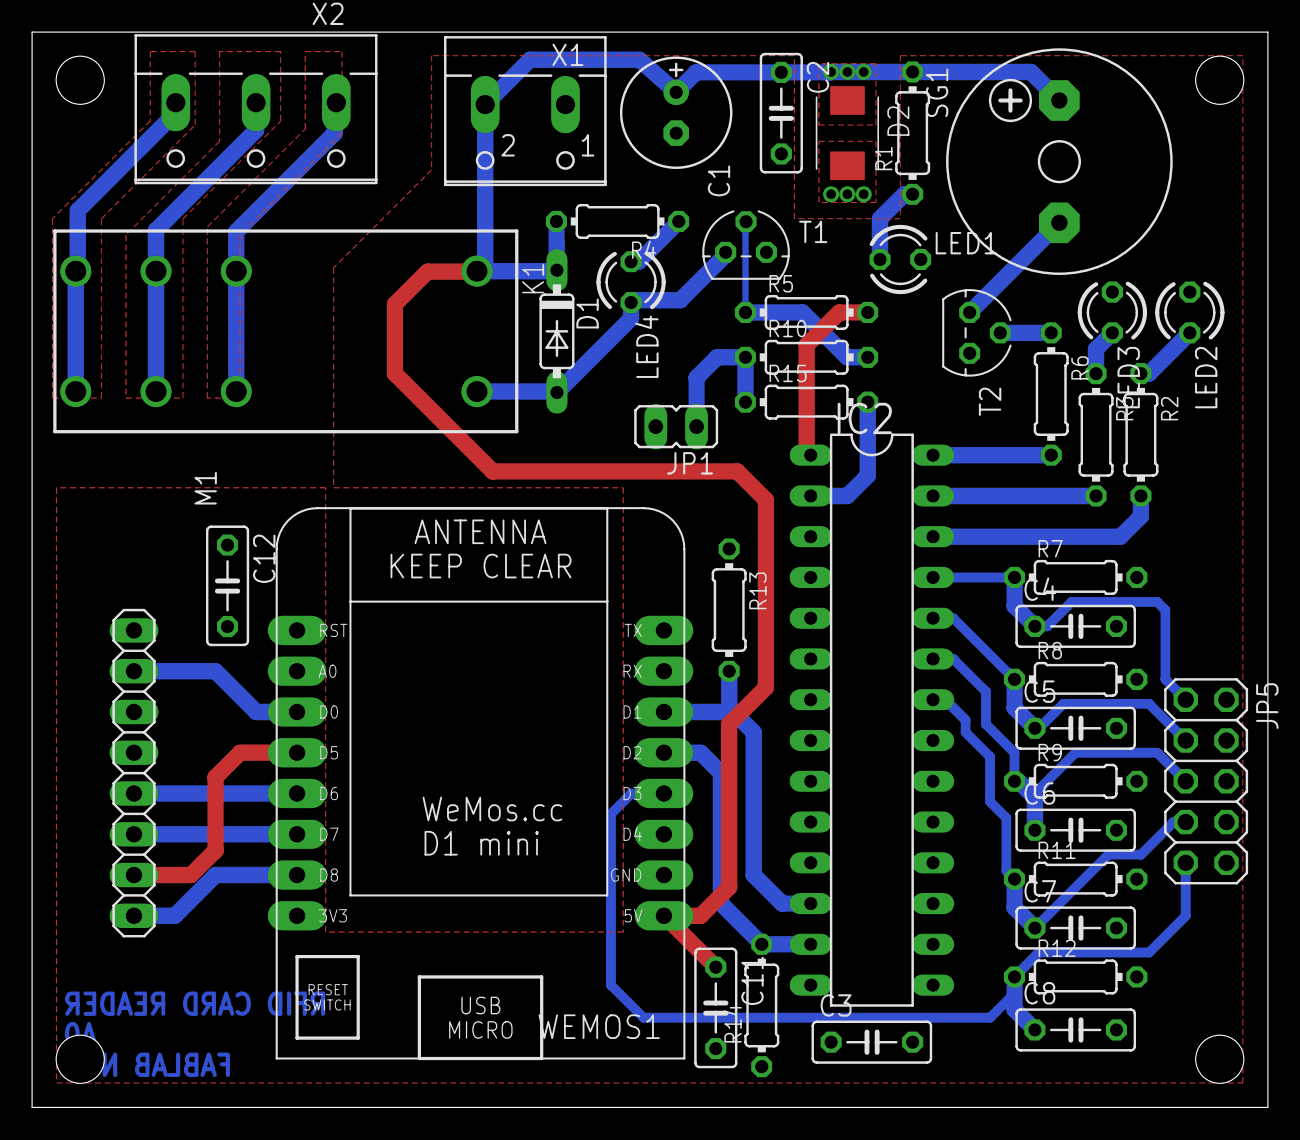
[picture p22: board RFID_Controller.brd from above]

Board: 2 copper layers, 77.0 x 67.0 mm, 42 parts (0 on the bottom side), 32 nets.

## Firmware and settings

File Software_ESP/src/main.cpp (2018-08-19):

// CONFIG: PIN layout
#define RST_PIN         D0  //16      // Configurable, see typical pin layout above
#define SS_PIN          D8  //15      // Configurable, see typical pin layout above
// Defaults for SPI
// MOSI  = 13	D7
// MISO  = 12	D6
// SCK   = 14	D5
#include <SPI.h>
#include <MFRC522.h>
#include <ESP8266Wifi.h>

#include <Wire.h>  // Wire is needed for I2C (TWI)
#include "Adafruit_MCP23017.h"


// To protect real passwords, config.h is not included on the github repository.
//   So if this file is not found, copy
//   example_config.h to config.h and adapt values
#include "example_config.h"
#include "GPIOHandler.h"
#include "CommunicationHandler.h"
#include "RFIDStateMachine.h"
#include "TimeoutHandler.h"

MFRC522 Cardreader(SS_PIN, RST_PIN);  // Create MFRC522 instance
MFRC522::Uid CurrentCard = {0};
GPIOHandler Ctrl;
RFIDState State;
RFIDTrigger Trigger;
WiFiClient Client;
TimeoutHandler Timeout;
CommunicationHandler Comm;

bool SameCard(){
	bool bOk = true;
	if(Cardreader.uid.size == CurrentCard.size
	&& Cardreader.uid.sak  == CurrentCard.sak){
		for(int i = 0; i < 10; i++){
			bOk = bOk && (Cardreader.uid.uidByte[i] == CurrentCard.uidByte[i]);
		}
		Serial.println("Cards are " + bOk ? "identical " : "not identical");
		return bOk;
	}else{
		return false;
	}
}
uint8_t GetState(){
	uint8_t commState;
	if(State == eStateRunning){
		commState = RFID_STATE_RUNNING;
	}else{
		commState = RFID_STATE_ERROR;
	}
	if(Ctrl.RelayState() == RelOn){
		commState |= RFID_STATE_RELAY_ON;
	}else{
		commState |= RFID_STATE_RELAY_OFF;
	}
	return commState;
}

void Verify(){
	Ctrl.LEDTxRx(LEDOn);
	Serial.println("Card verification");
	if(Comm.VerifyCard(Cardreader.uid.uidByte, Cardreader.uid.size, GetState())){
		Serial.println("Access granted");
		CurrentCard = Cardreader.uid;
		Ctrl.Relay(RelOn);
		Timeout.ResetTimeout();
		Ctrl.Buzzer(BuzzAck);
	}else{
		Serial.println("Access denied");
		Ctrl.Relay(RelOff);
		Ctrl.Buzzer(BuzzNak);
	}
	Ctrl.LEDTxRx(LEDOff);
}

void setup() {
	/* Initialize Serial
	 *   74880 is the baudrate of the bootloader. I set the application to the same value,
	 *   so you can see all messages at startup. As 74880 is not a common baud rate,
	 *   some terminal application may not support it. In this case, set baudrate to
	 *   a more common value, e.g. 115200.
	*/
	Serial.begin(74880);
	Serial.println("Setup");
	Ctrl.GPIOTest();
  WiFi.begin(ap_ssid, ap_password);
	State = eStateConnecting;
  Trigger = eTriggerOn;
	SPI.begin();				// Init SPI with default values
	Cardreader.PCD_Init();		// Init MFRC522
}

void loop(){
	//Serial.printf("Start\n");
	while(WiFi.status() != WL_CONNECTED){
		Serial.print(".");
		Ctrl.LEDConn(LEDOff);
		Ctrl.Buzzer(BuzzOff);
		Ctrl.Update();
		delay(100);
	}
  //Serial.printf("Wifi connected to %s\n", WiFi.localIP().toString().c_str());
	if(Ctrl.RelayBypassed()){
		Ctrl.Buzzer(BuzzAnnoy);
		Serial.printf("Relay Bypassed!");
		State = eStateInactive;
	}else{
		if(State == eStateInactive){
			Serial.println("Relay Bypassing resolved");
			Ctrl.Buzzer(BuzzOff);
			State = eStateRunning;
		}
	}
	//Serial.printf("Before Is Connected\n");
	//TO DO: Server connection and checking if data is available ?!
	//			 reading of enclosure switch (sabotage)
	if(!Comm.IsConnected()){
		Comm.Disconnect();
		if(!Comm.Connect(Server, Port)){
			State = eStateConnecting;
			Serial.println("Connecting to RFID Server ...");
		}else{
			Serial.println("Connection to RFID Server succeeded");
			Ctrl.LEDConn(LEDOn);
			//Client.println("Halo1bims!");
			State = eStateRunning;
		}
  }
//Serial.printf("Before Card Check\n");
	if( (State == eStateRunning) && Cardreader.PICC_IsNewCardPresent() && Cardreader.PICC_ReadCardSerial() ){
		Serial.println("Card detected");
		Cardreader.PICC_DumpToSerial(&(Cardreader.uid));
		if(Ctrl.RelayState() == RelOn){
			if(SameCard()){
				if(Timeout.TimeoutCritical()){
					Serial.println("Timeout reset");
					Timeout.ResetTimeout();
					Ctrl.Buzzer(BuzzAck);
				}else{
					Serial.println("Timeout decreased");
					Timeout.SetTimeoutCritical();
					Ctrl.Buzzer(BuzzWaitForUser);
				}
			}else{ //friendly fire
				 Verify();
			}
		}else{
			 Verify();
		}


	}
//Serial.printf("Before Timeout Check\n");
	if ( !Timeout.UpdateTimeout()){
		Serial.println("Timeout expired");
			Ctrl.Relay(RelOff);
			Ctrl.Buzzer(BuzzOff);
	}
	if ( Timeout.TimeoutCritical()){
		Serial.println("Timeout critical");
		Ctrl.Buzzer(BuzzWaitForUser);
	}
	//Serial.printf("Before Ctrl Update\n");
	Ctrl.Update();
	//Serial.printf("End\n");
}

/*
void loop() {
	if(WiFi.status() != WL_CONNECTED){
		State = eStateConnecting;
		Ctrl.LEDConn(LEDOff);
		Ctrl.Buzzer(BuzzOff);
		Ctrl.Update();
	}
	if(Ctrl.RelayBypassed()){
		Ctrl.Buzzer(BuzzLongBeeps);
		Serial.printf("Relay Bypassed!");
		State = eStateInactive;
	}

  switch(State){
		case eStateConnecting:
		  Serial.printf("State = Connecting");
			while (WiFi.status() != WL_CONNECTED)
		  {
		    delay(500);
		    Serial.print(".");
		  }
			if(Client.connect(Server, Port)){
				Serial.println("Connection to RFID Server succeeded");
				Client.println("Halo1bims!");
			}
			State = eStateRunning;
			Ctrl.LEDConn(LEDOn);
			break;
		case eStateRunning:
		  Serial.printf("State = Running");
			Ctrl.Buzzer(BuzzOff);
			if( Cardreader.PICC_ReadCardSerial() ){
				Cardreader.PICC_DumpToSerial(&(Cardreader.uid));
				Serial.printf("New Card present: Size = %d \n",Cardreader.uid.size);
				Serial.printf("UID = [");
				for(int i = 0; i < 10; i++){
					Serial.printf(" 0x%x",Cardreader.uid.uidByte[i]);
				}
				Serial.printf("] \n Sak= %d",Cardreader.uid.sak);
				State = eStateVerify;
				Ctrl.LEDTxRx(LEDOn);
			}else{
				Serial.printf("No card present");
				Ctrl.LEDTxRx(LEDOff);
			}
			break;
		case eStateVerify:
		  Serial.printf("State = Verify");
			//send card info to server
			if(true){ //check if server accepts card info
				CurrentCard = Cardreader.uid;
				Ctrl.Buzzer(BuzzShortBeepsPos);
			}else{
				Ctrl.Buzzer(BuzzShortBeepsNeg);
			}
			State = eStateCardPresent;
			break;
		case eStateCardPresent:
			Serial.printf("State = Card Present");
			switch(Trigger){
				case eTriggerOn:
					Serial.printf("Turn circuit on");
					Ctrl.Relay(RelOn);
					Trigger = eTriggerOff;
				break;
				case eTriggerOff:
					if (SameCard()){
						Serial.printf("Turn circuit off");
						Ctrl.Buzzer(BuzzRelOff);
						Ctrl.Relay(RelOff);
					}
					Trigger = eTriggerOn;
				break;
			}
			State = eStateRunning;
			break;
		case eStateInactive:
			State = eStateRunning;
			break;
		default:
			break;
	}
	delay(CYCLE_TIME);
	Ctrl.Update();

}*/

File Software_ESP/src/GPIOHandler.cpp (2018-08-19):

#include <GPIOHandler.h>
#include <Adafruit_MCP23017.h>
#include <Arduino.h>
#include <example_config.h>

GPIOHandler::GPIOHandler()
{
  gpio.begin();
  gpio.pinMode(CONN_LED_PIN, OUTPUT);
  gpio.pinMode(TXRX_LED_PIN, OUTPUT);
  gpio.pinMode(BUZZ_PIN, OUTPUT);
  gpio.pinMode(RELAY_PIN, OUTPUT);
  gpio.pinMode(RELAY_PIN_READ, INPUT);
  gpio.pullUp(RELAY_PIN_READ, HIGH);

  gpio.digitalWrite(CONN_LED_PIN, LOW);
  gpio.digitalWrite(TXRX_LED_PIN, LOW);
  gpio.digitalWrite(BUZZ_PIN, LOW);
  gpio.digitalWrite(RELAY_PIN, LOW);

  m_ConnLedTime = 0;
  m_TxRxLedTime = 0;
  m_BuzzTime = 0;
  m_ConnState = LEDMode::LEDOff;
  m_TxRxState = LEDMode::LEDOff;
  m_BuzzerState = BuzzerMode::BuzzOff;
  m_RelayState = RelayMode::RelOff;
  m_InitialRelOn = 1;

}

GPIOHandler::~GPIOHandler()
{

}
void GPIOHandler::GPIOTest(){
  gpio.digitalWrite(CONN_LED_PIN, LOW);
  delay(500);
  gpio.digitalWrite(CONN_LED_PIN, HIGH);
  gpio.digitalWrite(TXRX_LED_PIN, LOW);
  delay(500);
  gpio.digitalWrite(TXRX_LED_PIN, HIGH);
  BuzzerBeep(100, 1, 1);
}
void GPIOHandler::LEDConn(LEDMode mode)
{
  m_ConnState = mode;
  if(mode == LEDOn){
    gpio.digitalWrite(CONN_LED_PIN, LOW);
  }
  if(mode == LEDOff){
    gpio.digitalWrite(CONN_LED_PIN, HIGH);
  }
}
void GPIOHandler::LEDTxRx(LEDMode mode)
{
  m_TxRxState = mode;
  if(mode == LEDOn){
    gpio.digitalWrite(TXRX_LED_PIN, LOW);
  }
  if(mode == LEDOff){
    gpio.digitalWrite(TXRX_LED_PIN, HIGH);
  }
}
void GPIOHandler::Buzzer(BuzzerMode mode)
{
  if(m_BuzzerState != mode) //new mode, restart timer
  {
    m_BuzzTime = millis();
  }
  m_BuzzerState = mode;
}
void GPIOHandler::Relay(RelayMode mode)
{
  m_RelayState = mode;
}

bool GPIOHandler::RelayBypassed(){

  //Serial.printf(" Relay pin read %d ", gpio.digitalRead(RELAY_PIN_READ));
  if( ( m_RelayState == RelOff ) && ( gpio.digitalRead(RELAY_PIN_READ) == HIGH ) ){
    return true;
  }
  return false;
}
RelayMode GPIOHandler::RelayState(){
  return m_RelayState;
}

void GPIOHandler::Update()
{
  //Serial.println("Ctrl Update start");
  UpdateLed(CONN_LED_PIN, m_ConnState, &m_ConnLedTime);
  UpdateLed(TXRX_LED_PIN, m_TxRxState, &m_TxRxLedTime);
  //Serial.println("Before Update Buzzer");
  UpdateBuzzer();

  switch(m_RelayState){
    case RelOff:
      gpio.digitalWrite(RELAY_PIN, LOW);
      m_InitialRelOn = 1;
      break;
    case RelOn:
      gpio.digitalWrite(RELAY_PIN, HIGH);
      if(m_InitialRelOn){
        delay(Timeout_Block);
        m_InitialRelOn = 0;
      }
      break;
    break;
  }
}

void GPIOHandler::UpdateLed(uint8_t pin, LEDMode mode, uint16_t* time){
  switch(mode){
    case LEDOff:
      gpio.digitalWrite(pin, HIGH);
      //Serial.printf("Turning pin %d to low\n",pin);
      *time = 0;
      break;
    case LEDOn:
      gpio.digitalWrite(pin, LOW);
      *time = 0;
      break;
    case LEDBlink:
      m_ConnLedTime+=CYCLE_TIME;
      if(*time >= LED_BLINK_TIME_MS){
        gpio.digitalWrite(pin, !gpio.digitalRead(pin));
        *time = 0;
      }
    break;
  }
}
void GPIOHandler::UpdateBuzzer(){
  int iStartTime = millis();
  //Serial.printf("Buzzer state: %d\n",m_BuzzerState);
  switch(m_BuzzerState){
    case BuzzOff:
      gpio.digitalWrite(BUZZ_PIN, LOW);
      break;
    case BuzzOn:
      gpio.digitalWrite(BUZZ_PIN, HIGH);
      break;
    case BuzzConfirm:
      gpio.digitalWrite(BUZZ_PIN, HIGH);
      delay(1000);
      gpio.digitalWrite(BUZZ_PIN, LOW);
      m_BuzzerState = BuzzOff;
    break;
    case BuzzWaitForUser:

      if(gpio.digitalRead(BUZZ_PIN) == HIGH){

        if(millis() - m_BuzzTime > 3000){ //3s beep
          gpio.digitalWrite(BUZZ_PIN, LOW);
          m_BuzzTime = millis();
        }
      }else{
        if(millis() - m_BuzzTime > 2000){ //2s non-beep
          gpio.digitalWrite(BUZZ_PIN, HIGH);
          m_BuzzTime = millis();
        }
      }
      break;


    case BuzzAck:
      gpio.digitalWrite(BUZZ_PIN, HIGH); //blocking
      delay(2000);
      gpio.digitalWrite(BUZZ_PIN, LOW);
      m_BuzzerState = BuzzOff;
    break;
    case BuzzNak:
      BuzzerBeep(2000, 200, 2);
      gpio.digitalWrite(BUZZ_PIN, HIGH); //blocking, its ok, something went wrong
      delay(10000);
      gpio.digitalWrite(BUZZ_PIN, LOW);
      m_BuzzerState = BuzzOff;
    break;
    case BuzzAnnoy:
      if(millis() - m_BuzzTime > 60000){
        gpio.digitalWrite(BUZZ_PIN, HIGH);
        delay(5000);
        gpio.digitalWrite(BUZZ_PIN, LOW);
        m_BuzzTime = millis();
      }
      break;
  }
}
void GPIOHandler::BuzzerBeep(uint16_t tOn, uint16_t tOff, uint8_t tCount){
  for(uint8_t i = 0; i < tCount; i++){
    gpio.digitalWrite(BUZZ_PIN, HIGH);
    delay(tOn);
    gpio.digitalWrite(BUZZ_PIN, LOW);
    if(tCount > 1){
      delay(tOff);
    }
  }
  m_BuzzTime = 0;
  m_BuzzerState = BuzzOff;
}

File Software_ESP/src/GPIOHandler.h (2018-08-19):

#ifndef GPIOHANDLER_H
#define GPIOHANDLER_H

#include "Adafruit_MCP23017.h"

#define GPB_OFFSET 8                  //offset for GPB* pins
#define CONN_LED_PIN 6                //GPA6
#define TXRX_LED_PIN 5                //GPA5
#define BUZZ_PIN 7                    //GPA7
#define RELAY_PIN GPB_OFFSET + 0      //GPB0
#define RELAY_PIN_READ GPB_OFFSET + 1 //GPB1

#define CYCLE_TIME         100
#define BUZZ_SHORT_TIME_MS 100
#define BUZZ_LONG_TIME_MS  1000 * 60 //every minute
#define LED_BLINK_TIME_MS  200

typedef enum tagLEDMode{
  LEDOff = 0,
  LEDOn,
  LEDBlink
}LEDMode;

typedef enum tagBuzzerMode{
  BuzzOff = 0,
  BuzzOn,
  BuzzConfirm,
  BuzzWaitForUser,
  BuzzAck,
  BuzzNak,
  BuzzAnnoy
}BuzzerMode;

typedef enum tagRelayMode{
  RelOff = 0,
  RelOn
}RelayMode;

class GPIOHandler{
public:
  GPIOHandler(void);
  virtual ~GPIOHandler(void);

  void LEDConn(LEDMode mode);
  void LEDTxRx(LEDMode mode);
  void Buzzer(BuzzerMode mode);
  void Relay(RelayMode mode);
  bool RelayBypassed();
  RelayMode RelayState();
  void GPIOTest();
  void Update();

private:
  void UpdateLed(uint8_t pin, LEDMode mode, uint16_t* time);
  void UpdateBuzzer();
  void BuzzerBeep(uint16_t tOn, uint16_t tOff, uint8_t tCount); //tOn = on time in ms, tOff = off time in ms, tCount = no of repeats
  LEDMode m_ConnState;
  LEDMode m_TxRxState;
  BuzzerMode m_BuzzerState;
  RelayMode m_RelayState;
  uint16_t m_ConnLedTime;
  uint16_t m_TxRxLedTime;
  uint8_t m_InitialRelOn;
  int m_BuzzTime;

  Adafruit_MCP23017 gpio;
};
#endif //GPIOHANDLER_H

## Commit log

2017-11-03 -first commit. Added TechSpec, board schematic and layout, pdf manuals for infos about several parts
    [RFID_Controller.brd, RFID_Controller.sch]
2017-11-22 -add: I2C Expander for more GPIOs -add: input for sabotage detection ( switch for enclosure cover ) -add: 2 more inputs for possible extensions -mod: additional resistor in pull-up path of relais tra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
    [RFID_Controller.brd, RFID_Controller.sch]
2017-11-22 -del: old pictures of layout and schematic -add: new pdfs for current layout and schematic
2017-11-24 -mod: 2 additional Extra GPIO's -mod: replaced 3 single 1x2 pin headers with 2x5 pin header -mod: maximized copper area of relay contacts -info: Schematic verified by Ian Hubbertz
    [RFID_Controller.brd, RFID_Controller.sch]
2017-11-24 -mod: modifies according to Roberts recommendations
    [RFID_Controller.brd, RFID_Controller.sch]
2017-11-26 -mod: more distance between drill and HV (upper left corner) -mod: TVS diode instead of Z-Diode -fix: additional resistor to SW Output pin to avoid short circuits. SW input pin measures now full volt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
    [RFID_Controller.brd, RFID_Controller.sch]
2017-12-04 -mod: Board layout and Schematic in ELAB optimized
    [RFID_Controller.brd, RFID_Controller.sch]
2017-12-10 First version of ESP-Software using Automaton
    - I also restructed the documentation to doc folder and sub-folders
    - To compile, install platfomio and run "pio run", to upload run "pio
    run -t upload".
    [RFID_Controller.brd, RFID_Controller.sch]
2017-12-31 Netzteil dummy.
    [Netzteil.fcstd]
2017-12-31 MFRC522-Module dummy. Hope 60mm x 40mm is correct.
    [MFRC522-Module.fcstd, MFRC522-Module.stl]
2017-12-31 Relais dummy
    [Relais-FTR-K1.fcstd, Relais-FTR-K1.stl]
2018-01-04 first study how things could fit inside...
    [Gehaeuse.fcstd, pcb-layout.fcstd]
2018-01-04 second study how things could fit inside... have the sensitiv area more in the center of the box
    [Gehaeuse.fcstd]
2018-01-04 second study how things could fit inside... have the sensitiv area really in the center of the box
    [Gehaeuse.fcstd]
2018-01-04 small adjustments.
    [Gehaeuse.fcstd]
2018-01-04 two halfs of the housing done!
    [Gehaeuse.fcstd, gehaeuse_links.stl, gehaeuse_rechts.stl]
2018-01-07 screws, interieor, clearances
    [Gehaeuse.fcstd, gehaeuse_links.stl, gehaeuse_rechts.stl]
2018-01-08 moved front screw from left to right, so that both rails are in left housing. Added access openings in the rails for the screws below. All components are built into the left housing part. The right w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
    [Gehaeuse.fcstd, frontplatte.stl, gehaeuse_links.stl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]
2018-01-09 Truecon version of the left part added
    [Gehaeuse.fcstd, gehaeuse_links_truecon.stl]
2018-01-09 screenshots added.
    [led_halter.stl, led_halter_3mm.stl, led_halter_5mm.stl]
2018-01-09 Imported 3D+File+NAC3PX.stp 3D+File+SCNAC-PX.stp Strichzeichnung+NAC3MX-W.png from Neutrik. Used with permission:
    neutrik@neutrik.de <neutrik@neutrik.de>
    12:05 (vor 3 Stunden)
    an mich
    Guten Tag Herr Weigert,
    vielen Dank für Ihre Nachricht und Ihr Vorhaben. Die Einbindung der STEP-Dateien geht so in Ordnung.
    Mit freundlichen Grüßen | Best regards
    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
    [Gehaeuse.fcstd]
2018-01-11 5mm tieferes gehäuse. Sollbruchstellen drin.
    [Gehaeuse.fcstd, gehaeuse_links.stl, gehaeuse_links_truecon.stl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]
2018-01-20 -mod: update to v1.0 final version of schematic and layout
2018-08-13 svg der linken seite dazu, Leider immernoch Pultform.
    [Gehaeuse.fcstd]
2018-08-19 -mod: fixed a bug in the schematic/layout
    [RFID_Controller.brd, RFID_Controller.sch]
